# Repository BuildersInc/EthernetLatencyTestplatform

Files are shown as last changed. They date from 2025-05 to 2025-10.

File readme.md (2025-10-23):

# Ethernet Latency Testplatform

Used to measure the time difference
within the Ethernet communication between
two uC's

Created for my Bachelor Thesis

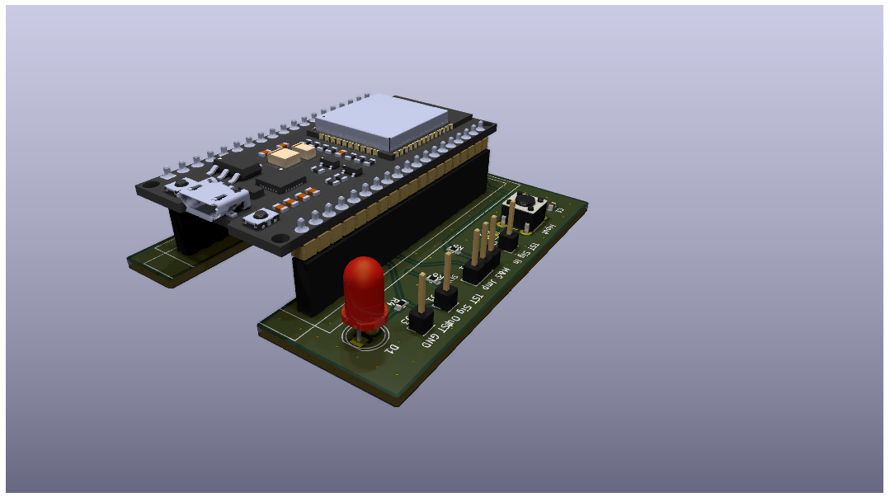
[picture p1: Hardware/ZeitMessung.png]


## External Components

- [ESP32 WROOM32](https://www.amazon.de/dp/B0D8635YZ6)
- [LAN8720 Board](https://www.amazon.de/TECNOIOT-Ethernet-Transceiver-Interface-Development/dp/B07VN9Q4QK)

## ESP 32 Pinout

| GPIO | Function |
|---|--- |
|00 |RETCLK |
|12 |Output detection |
|13 |Input detection |
|14 |Master & Slave |
|17 |NC		 		|
|18 |MDC |
|19 |TX 0 |
|21 |TX Enable |
|22 |TX 1 |
|23 |MDIO |
|25 |RX 0 |
|26 |RX  1 |
|27 |CRS |

## Necessary Modifications

- Remove ClockGen from LAN8720 Board and use ESP32 as source

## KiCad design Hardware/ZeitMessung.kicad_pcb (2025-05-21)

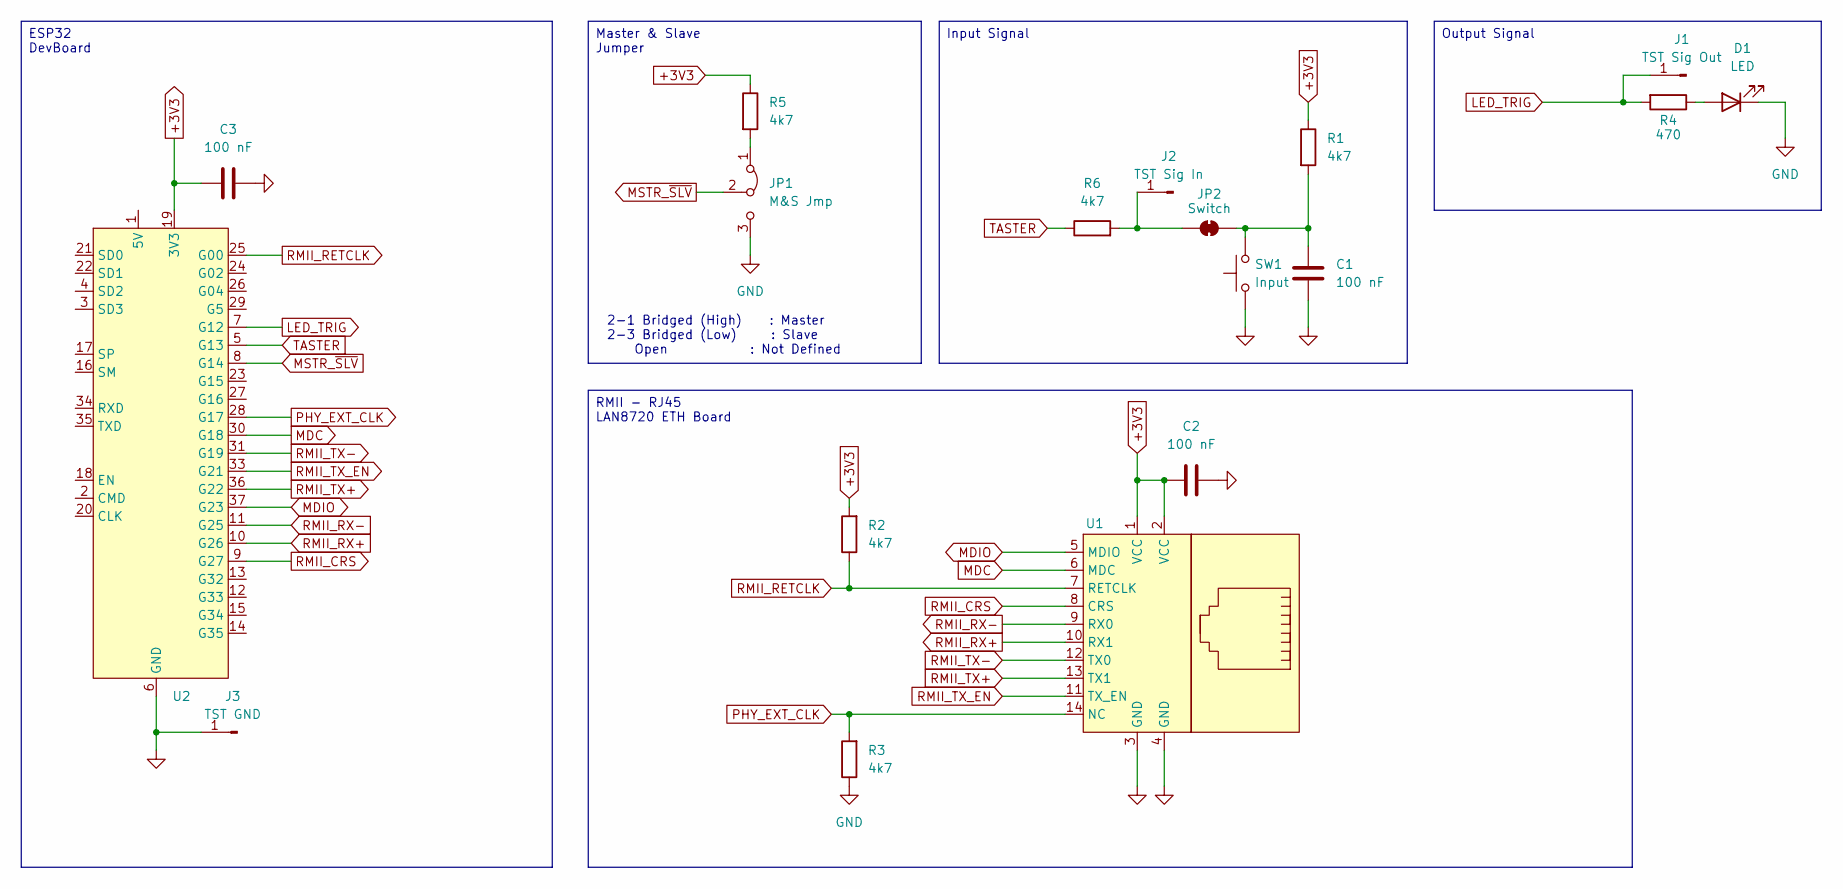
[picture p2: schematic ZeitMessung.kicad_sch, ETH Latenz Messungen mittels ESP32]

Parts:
C1, C2, C3: 100 nF; C_0603_1608Metric
D1: LED; LED_D5.0mm
J1: TST Sig Out; PinHeader_1x01_P2.54mm_Vertical
J2: TST Sig In; PinHeader_1x01_P2.54mm_Vertical
J3: TST GND; PinHeader_1x01_P2.54mm_Vertical
JP1: M&S Jmp; PinHeader_1x03_P2.54mm_Vertical
JP2: Switch; SolderJumper-2_P1.3mm_Open_RoundedPad1.0x1.5mm
R1, R2, R3, R5, R6: 4k7; R_0603_1608Metric
R4: 470; R_0603_1608Metric
SW1: Input; SW_PUSH_6mm
U1: LAN8720 DevBoard
U2: ESP32-WROOM

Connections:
+3V3: C2.1, C3.1, R1.1, R2.2, R5.1, U1.1 (VCC), U1.2 (VCC), U2.19 (3V3)
GND: C1.1, C2.2, C3.2, D1.1 (K), J3.1, JP1.3 (B), R3.1, SW1.1, U1.3 (GND), U1.4 (GND), U2.6 (GND)
LED_TRIG: J1.1, R4.2, U2.7 (G12)
MDC: U1.6 (MDC), U2.30 (G18)
MDIO: U1.5 (MDIO), U2.37 (G23)
MSTR_~SLV: JP1.2 (C), U2.8 (G14)
unnamed: D1.2 (A), R4.1
unnamed: J2.1, JP2.1 (A), R6.2
unnamed: JP1.1 (A), R5.2
unnamed: C1.2, JP2.2 (B), R1.2, SW1.2
PHY_EXT_CLK: R3.2, U1.14 (NC), U2.28 (G17)
RMII_CRS: U1.8 (CRS), U2.9 (G27)
RMII_RETCLK: R2.1, U1.7 (RETCLK), U2.25 (G00)
RMII_RX+: U1.10 (RX1), U2.10 (G26)
RMII_RX-: U1.9 (RX0), U2.11 (G25)
RMII_TX+: U1.13 (TX1), U2.36 (G22)
RMII_TX-: U1.12 (TX0), U2.31 (G19)
RMII_TX_EN: U1.11 (TX_EN), U2.33 (G21)
TASTER: R6.1, U2.5 (G13)

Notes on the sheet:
2-1 Bridged (High) : Master 2-3 Bridged (Low) : Slave Open : Not Defined
ESP32 DevBoard
Output Signal
RMII - RJ45 LAN8720 ETH Board
Input Signal
Master & Slave Jumper

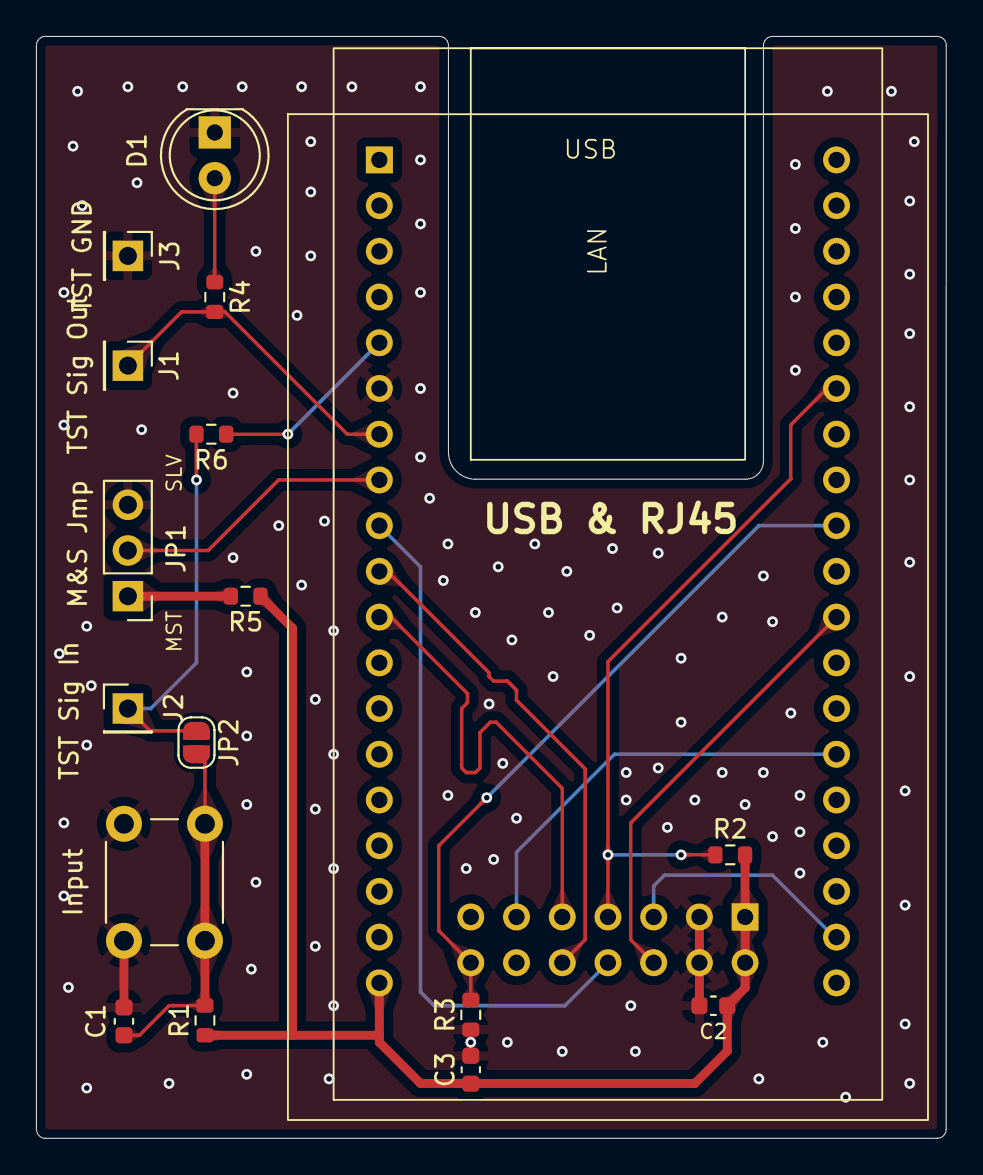
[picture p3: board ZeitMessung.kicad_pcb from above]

Board: 4 copper layers, 50.5 x 61.2 mm, 18 parts (0 on the bottom side), 19 nets.

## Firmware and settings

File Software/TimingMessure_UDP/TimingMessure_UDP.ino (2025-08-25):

#include <ArduinoJson.h>
#include <EthernetESP32.h>
#include <HTTPClient.h>
#include <WebServer.h>


#define USE_SERIAL Serial

#define DBG_SERVER 0
#define MASTER_SLAVE 1

// #define ETH_TARGET DBG_SERVER
#define ETH_TARGET MASTER_SLAVE


/* Messurement Pins */
#define MASTER_AND_SLAVE 14
#define ALIVE_LED 13
#define SIG_OUT 12
#define PHY_EN 5

#define UDP_TX_PACKET_MAX_SIZE 860

typedef enum {
  NOT_DEFINED,
  MASTER,
  SLAVE
} MODE;

MODE mode = MASTER;

int iteration = 0;

// IPAddress gateway(0, 0, 0, 0);
// IPAddress subnet(0, 0, 0, 0);
// IPAddress dns(0, 0, 0, 0);
// byte macMaster[] = { 0xDE, 0xAD, 0xBE, 0xEF, 0xFE, 0xED };
// byte macSlave[] = { 0xC0, 0x0F, 0xFE, 0xEB, 0xAB, 0xE0 };
IPAddress master(192, 168, 178, 150);

#if ETH_TARGET == DBG_SERVER
IPAddress slave(169, 254, 235, 86);
#else
// IPAddress slave(192, 168, 178, 24);

IPAddress slave(255, 255, 255, 255);
#endif

// For Device B
// EMACDriver driver(
//   ETH_PHY_LAN8720, 18, 23, 17, EMAC_APPL_CLK_OUT_GPIO, EMAC_CLK_OUT);

// For any other Device
EMACDriver driver(
  ETH_PHY_LAN8720, 18, 23, 17, EMAC_CLK_IN_GPIO, EMAC_CLK_EXT_IN);


unsigned int udp_port = 8080;
uint8_t packetBuffer[UDP_TX_PACKET_MAX_SIZE];
uint8_t NormalMessage[] = "YouThere?";
uint8_t NormalAnswer[] = "YesIAm!";
uint8_t AlarmMsg[] = "Alarm!";

EthernetUDP Udp;

void handle_alarm(void) {
}

int handle_calc(int a, int b) {
  return a + b;
}

void ping_on_pin(uint8_t pin) {
  digitalWrite(pin, HIGH);
  digitalWrite(pin, LOW);
}

void setup() {

  USE_SERIAL.begin(115200);
  Ethernet.init(driver);

  pinMode(ALIVE_LED, OUTPUT);
  pinMode(SIG_OUT, OUTPUT);
  pinMode(MASTER_AND_SLAVE, INPUT);

  // Set Board to master or Slave
  if (HIGH == digitalRead(MASTER_AND_SLAVE)) {
    mode = MASTER;
  } else {
    mode = SLAVE;
  }

  if (MASTER == mode) {
    USE_SERIAL.println("CHIP IN MASTER MODE");
    Ethernet.begin();
    // Ethernet.begin(master);
    // Ethernet.begin(macMaster, master, dns, gateway, subnet);
    USE_SERIAL.printf("Target will be, %d.%d.%d.%d\n", slave[0], slave[1], slave[2], slave[3]);
  } else if (SLAVE == mode) {
    USE_SERIAL.println("CHIP IN SLAVE MODE");
    Ethernet.begin();
    // Ethernet.begin(slave);
    // Ethernet.begin(macSlave, slave, dns, gateway, subnet);
    USE_SERIAL.printf("Master will be, %d.%d.%d.%d\n", master[0], master[1], master[2], master[3]);
    Udp.begin(udp_port);
  } else {
    USE_SERIAL.println("ERROR in Master Slave Select");
    while (1)
      ;
  }
  USE_SERIAL.println("Setup Complete");
  USE_SERIAL.println(Ethernet);
  if (Ethernet.hardwareStatus() == EthernetHardwareFound) {
    digitalWrite(ALIVE_LED, HIGH);
  } else {
    digitalWrite(ALIVE_LED, LOW);
  }
}

void loop() {
  // put your main code here, to run repeatedly:

  if (MASTER == mode) {
    Udp.beginPacket(slave, udp_port);
    if (5 == iteration) {
      iteration = 0;
      if (Udp.write(AlarmMsg, sizeof(AlarmMsg))) {
        USE_SERIAL.printf("Alarm Send\r\n");
      } else {
        USE_SERIAL.printf("Failed Alarm Send\r\n");
      }
    } else {
      if (Udp.write(NormalMessage, sizeof(NormalMessage))) {
        USE_SERIAL.printf("Send normal packet number: %i\r\n", iteration);
        iteration++;
      } else {
        USE_SERIAL.printf("FAILED packet number: %i\r\n", iteration);
      }
    }
    Udp.endPacket();
    delay(2500);

  }

  else if (SLAVE == mode) {
    int packetSize = Udp.parsePacket();
    if (packetSize) {
      Udp.read(packetBuffer, UDP_TX_PACKET_MAX_SIZE);

      if (NULL != strstr("Alarm!", (const char*)packetBuffer)) {
        // Alarm Message recv
        ping_on_pin(SIG_OUT);
        return;
      }
      Udp.beginPacket(Udp.remoteIP(), Udp.remotePort());
      Udp.write(NormalAnswer, sizeof(NormalAnswer));
      Udp.endPacket();
      USE_SERIAL.printf("Recv Packet with message: %s \r\n", packetBuffer);
    }
  }
}

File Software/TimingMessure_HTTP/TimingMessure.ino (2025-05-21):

// /* Ethernet Pins */
// #define ETH_PHY_TYPE ETH_PHY_LAN8720
// #define ETH_PHY_ADDR  -1
// #define ETH_PHY_MDC   18
// #define ETH_PHY_MDIO  23
// #define ETH_PHY_POWER -1
// #define ETH_CLK_MODE  ETH_CLOCK_GPIO0_OUT
// // #define ETH_NAME "ESP-Ethernet-2"

// #include <ETH.h>

#include <EthernetESP32.h>
#include <HTTPClient.h>
#include <WebServer.h>
#include <ArduinoJson.h>

#define USE_SERIAL Serial

// #define ETH_TARGET DBG_SERVER
#define ETH_TARGET MASTER_SLAVE

/* Messurement Pins */
#define MASTER_AND_SLAVE  14
#define SIG_IN            13
#define SIG_OUT           12


typedef enum {NOT_DEFINED, MASTER, SLAVE} MODE;
MODE mode = MASTER;

static bool eth_connected = false;
//variables to keep track of the timing of recent interrupts
unsigned long button_time = 0;  
unsigned long last_button_time = 0;
int iteration = 0; 

IPAddress master      (192, 168, 178, 150);
IPAddress slave       (192, 168, 178, 151);
IPAddress dbg_server  (192, 168, 178, 190);

WebServer server(8080);
EMACDriver driver(ETH_PHY_LAN8720, 18, 23, -1, EMAC_APPL_CLK_OUT_GPIO, EMAC_CLK_OUT);

const String payload = "{\"num1\": 10, \"num2\": 20}";
StaticJsonDocument<1024> jsonDocument;

#define BUFFER_SIZE 40
char* buffer = (char*)malloc(BUFFER_SIZE * sizeof(char));

HTTPClient http_calc;
HTTPClient http_error;

void start_http()
{
  static bool server_running = false;
  if (server_running) return;
#if ETH_TARGET == DBG_SERVER
    // http_calc.begin("http://192.168.178.190:8080/calculate");
    // http_error.begin("http://192.168.178.190:8080/calculate");
    // http_calc.begin("http://www.example.com/index.html");
#elif ETH_TARGET == MASTER_SLAVE
    http_calc.begin("http://192.168.178.20:8080/calculate");
    http_error.begin("http://192.168.178.20:8080/error");
#endif
  if (!server_running) server_running = true;
}

void IRAM_ATTR alarm_isr()
{
  // button_time = millis();
  // if (250 > (button_time - last_button_time))
  // {
  //   return;
  // }
  // last_button_time = button_time;

  // Send Alarm Packet#
  http_error.begin("http://192.168.178.151:8080/error");

  int http_code = http_error.POST("ERROR_ALARM");
  USE_SERIAL.println("Sending Alarm");
  http_error.end();
}

void handle_alarm(void)
{
  USE_SERIAL.println("Error Occured");
  digitalWrite(SIG_OUT, HIGH);
  digitalWrite(SIG_OUT, LOW);
}

void handle_calculation(void)
{
  String body = server.arg("plain");
  deserializeJson(jsonDocument, body);
  int num1 = jsonDocument["num1"];
  int num2 = jsonDocument["num2"];
  int result = num1 + num2;
  USE_SERIAL.printf("%d + %d = %d\n", num1, num2, result);
  sprintf(buffer, "{\"sum\": %d}", result);

  server.send(200, "application/json", buffer);
}


void setup() 
{
  
  USE_SERIAL.begin(115200);
  Ethernet.init(driver);

  pinMode(MASTER_AND_SLAVE, INPUT);
  pinMode(SIG_OUT, OUTPUT);
  pinMode(SIG_IN, OUTPUT);
  digitalWrite(SIG_OUT, LOW);

  // Set Board to master or Slave
  if (HIGH == digitalRead(MASTER_AND_SLAVE))
  {
    mode = MASTER;
  } 
  else 
  {
    mode = SLAVE;
  }

  if (MASTER == mode)
  {
    USE_SERIAL.println("CHIP IN MASTER MODE");
    Ethernet.begin(master);
  } 
  else if (SLAVE == mode)
  {
    USE_SERIAL.println("CHIP IN SLAVE MODE");
    Ethernet.begin(slave);
    server.on("/calculate", HTTP_POST, handle_calculation);
    server.on("/error", HTTP_POST, handle_alarm);
    server.begin();
  }
  else 
  {
    USE_SERIAL.println("ERROR in Master Slave Select");
    while(1);
  }
  USE_SERIAL.println("Setup Complete");
  USE_SERIAL.println(Ethernet);

}

void loop() {


  if (MASTER == mode)
  {
    // start_http();
    http_calc.begin("http://192.168.178.151:8080/calculate");

    USE_SERIAL.println("Start HTTP");
    http_calc.addHeader("Content-Type", "text/plain");
    int http_code = http_calc.POST(payload);

    USE_SERIAL.printf("[HTTP] GET... code: %d\n", http_code);
    if (0 < http_code) 
    {
      if (HTTP_CODE_OK == http_code) 
      {
        String payload = http_calc.getString();
        USE_SERIAL.println(payload);
        digitalWrite(SIG_IN, LOW);

      }
    } 
    else 
    {
      USE_SERIAL.printf("[HTTP] GET... failed, error: %s\n", http_calc.errorToString(http_code).c_str());
    }
    http_calc.end();
    delay(2500);
    iteration += 1;

    if (5 == iteration)
    {
      USE_SERIAL.println("Sending Alarm");

      digitalWrite(SIG_IN, HIGH);
      digitalWrite(SIG_IN, LOW);
      http_error.begin("http://192.168.178.151:8080/error");
      int http_code = http_error.POST("ERROR_ALARM");
      http_error.end();
      iteration = 0;
    }
    USE_SERIAL.printf("%i \n", iteration);
    // End Master Loop
  }
  else if (SLAVE == mode)
  {
	  server.handleClient();
    // End Slave Loop
  }
}
